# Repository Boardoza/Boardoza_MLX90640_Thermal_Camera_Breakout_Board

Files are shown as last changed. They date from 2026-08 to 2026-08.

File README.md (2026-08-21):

# Boardoza MLX90640 Thermal Camera Breakout Board

The **Boardoza MLX90640 Breakout Board** is a compact and high-performance **thermal imaging sensor board** built around the **Melexis MLX90640** far-infrared sensor array. Featuring a **32x24 pixel thermal resolution**, this breakout board delivers **768 independent temperature measurement points** for accurate non-contact thermal analysis and heat mapping applications.

Designed for compatibility with both **3.3V and 5V systems**, the board communicates through a high-speed **I<sup>2</sup>C interface** and supports refresh rates up to **64Hz**. With its wide temperature sensing range and integrated thermal array, the MLX90640 is ideal for applications such as industrial monitoring, predictive maintenance, occupancy detection, smart home systems, thermal visualization, robotics, and embedded sensing solutions.

## [Click here to purchase!](https://www.ozdisan.com/ureticiler/boardoza)

| Front Side | Back Side |
|:---:|:---:|
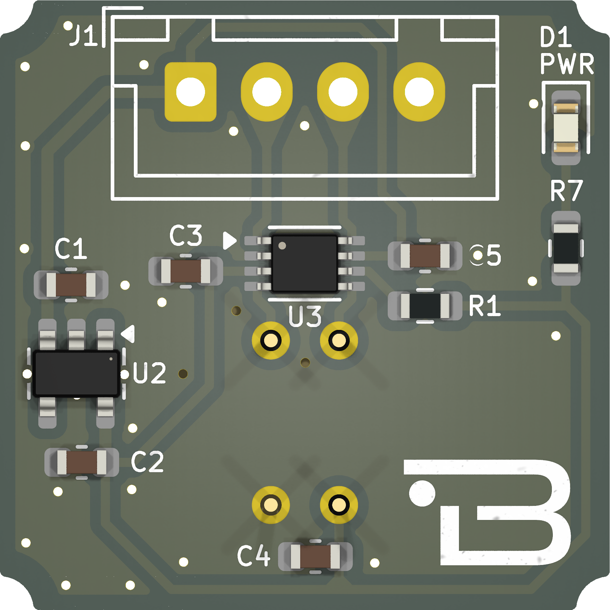
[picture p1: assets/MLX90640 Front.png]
MLX90640 Front
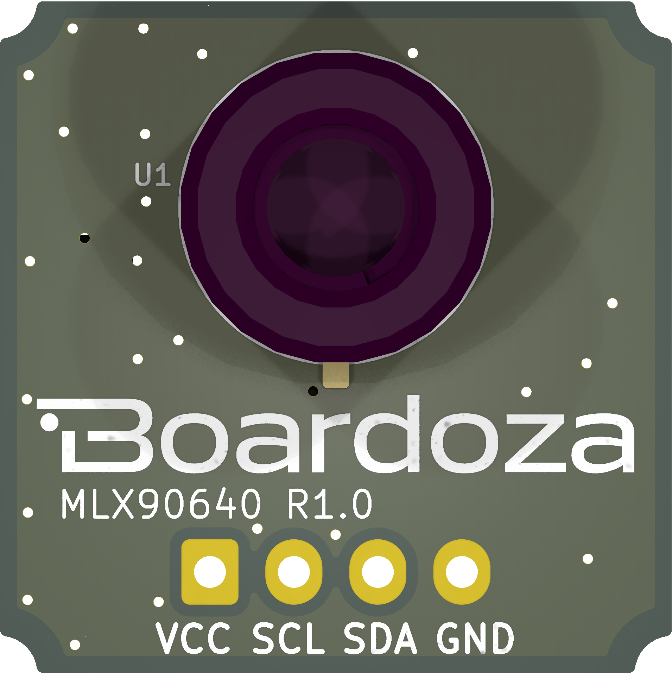
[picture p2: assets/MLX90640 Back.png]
MLX90640 Back
|  |  |

---

## Key Features

- **32x24 Thermal Imaging Array:** Captures 768 individual infrared temperature points for detailed thermal analysis.
- **Wide Temperature Measurement Range:** Measures object temperatures from **-40°C to +300°C** without physical contact.
- **Integrated Thermal Camera Functionality:** Enables compact thermal vision applications without requiring external optics.
- **Fast Refresh Rates:** Adjustable frame rates from **0.5Hz to 64Hz** for dynamic thermal monitoring.
- **Wide Compatibility:** Supports both **3.3V and 5V logic systems** for easy integration with popular development boards.
- **I<sup>2</sup>C Communication:** Supports I<sup>2</sup>C speeds up to **1MHz** for responsive thermal data transfer.
- **Wide Field of View:** Provides a **55° horizontal (X-axis)** and **35° vertical (Y-axis)** viewing angle for broader thermal coverage.  

---

## Technical Specifications

**Model:** MLX90640  
**Manufacturer:** Boardoza  
**Manufacturer IC:** Melexis  
**Functions:** Far-Infrared Thermal Imaging Sensor Array  
**Sensor Resolution:** 32 x 24 Pixels (768 Pixels Total)  
**Measurement Range:** -40°C to +300°C  
**Field of View (FoV):** 55° (X-axis) × 35° (Y-axis)  
**Interface:** I<sup>2</sup>C  
**I<sup>2</sup>C Clock Speed:** Up to 1 MHz  
**Refresh Rate:** 0.5Hz to 64Hz  
**Supply Voltage (VCC):** 3.3V to 5.5V DC  
**Logic Voltage Level:** 3.3V / 5V Compatible  
**Typical Current Consumption:** Less than 25mA   
**Operating Temperature:** -40°C to +85°C  
**Board Dimensions:** 20mm x 20mm  

---

## Board Pinout

### ( J1 ) I<sup>2</sup>C Connector

| Pin Number | Pin Name | Description |
|:---:|:---:|---|
| 1 | VCC | Voltage Supply Input |
| 2 | SCL | I<sup>2</sup>C Serial Clock |
| 3 | SDA | I<sup>2</sup>C Serial Data |
| 4 | GND | Ground |

---

## Board Dimensions

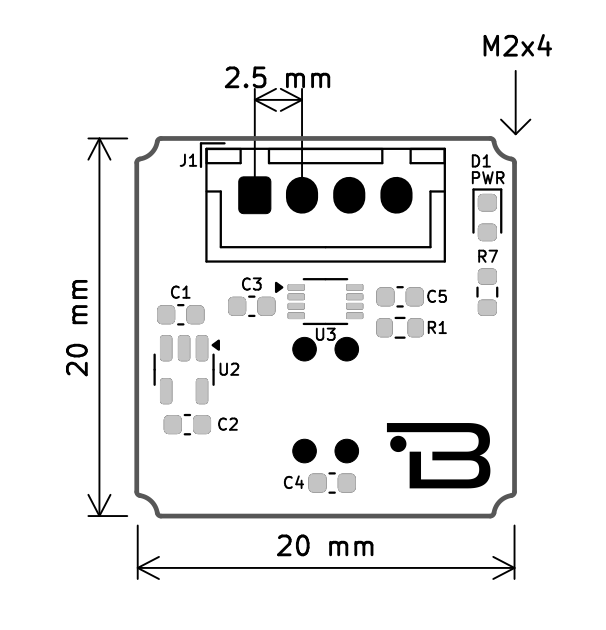
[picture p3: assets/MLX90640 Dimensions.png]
MLX90640 Board Dimensions


---

## Step Files

[Boardoza MLX90640.step](./assets/MLX90640%20Step.step)

---

## Datasheet

[MLX90640 Datasheet.pdf](./assets/MLX90640%20Datasheet.pdf)  
[TLV73333PDBVR Datasheet.pdf](./assets/TLV73333PDBVR%20Datasheet.pdf)  
[TXS0102DCU Datasheet.pdf](./assets/TXS0102DCU%20Datasheet.pdf)  

---

## Version History

- V1.0.0 - Initial Release

---

## Support

- If you have any questions or need support, please contact <support@boardoza.com>

---

## **License**

This repository contains both hardware and software components:

### **Hardware Design**

[][cc-by-sa]

All hardware design files are licensed under [Creative Commons Attribution-ShareAlike 4.0 International License][cc-by-sa].

[cc-by-sa]: http://creativecommons.org/licenses/by-sa/4.0/
[cc-by-sa-shield]: https://img.shields.io/badge/License-CC%20BY--SA%204.0-lightgrey.svg

### **Software/Firmware**

[][bsd]

All software and firmware are licensed under [BSD 3-Clause License][bsd].

[bsd]: https://opensource.org/licenses/BSD-3-Clause
[bsd-shield]: https://img.shields.io/badge/License-BSD%203--Clause-blue.svg

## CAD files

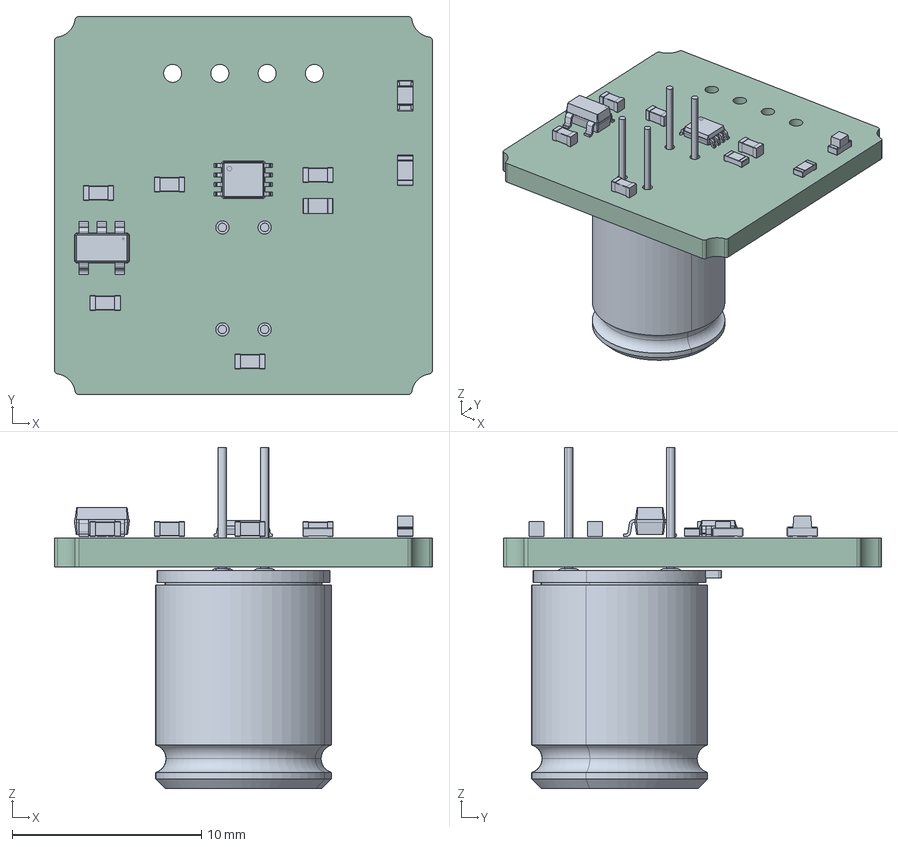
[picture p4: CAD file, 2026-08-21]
assets/MLX90640 Step.step
20.0 x 20.0 x 18.1 mm
R_0603_1608Metric x 2
VSSOP-8_2.3x2mm_P0.5mm
C_0603_1608Metric x 5
LED_0603_1608Metric
SOT-23-5
kicad_embedded_38222028E3E54F88FE30E4AF7AF088A7
kibot_x39tdho__PCB

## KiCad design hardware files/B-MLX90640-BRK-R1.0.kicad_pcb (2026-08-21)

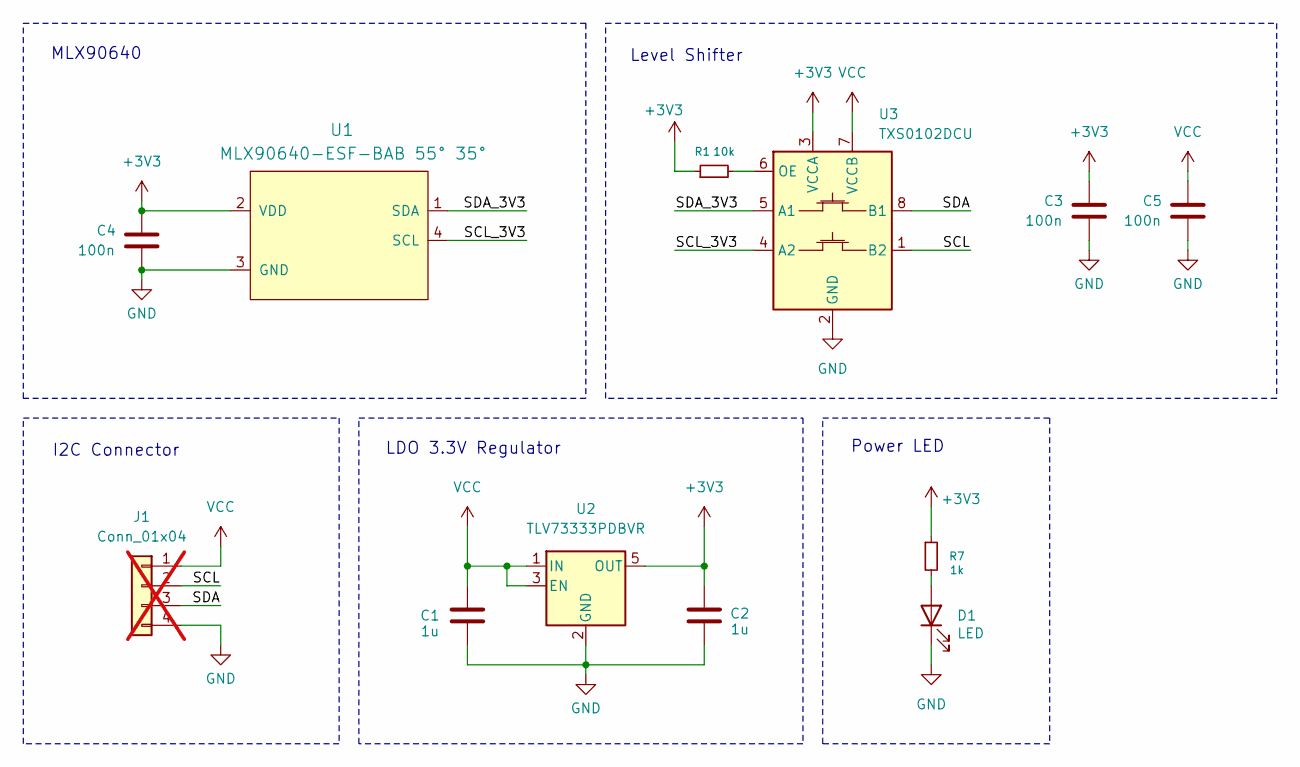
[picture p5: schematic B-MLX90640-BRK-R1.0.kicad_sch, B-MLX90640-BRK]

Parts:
C1, C2: 1u; C_0603_1608Metric; MANUFACTURER PART CL10A105KO8NNNC
C3, C4, C5: 100n; C_0603_1608Metric; MPN CL10B104KB8WPNC
D1: LED; LED_0603_1608Metric; MANUFACTURER PART LTST-C190KRKT
J1: Conn_01x04; JST_XH_B4B-XH-A_1x04_P2.50mm_Vertical; MPN L-KLS1-2.50-04-SB; not fitted
R1: 10k; R_0603_1608Metric; MANUFACTURER PART 0603SAJ0471T5E
R7: 1k; R_0603_1608Metric; MANUFACTURER PART 0603SAJ0471T5E
U1: MLX90640-ESF-BAB 55° 35°; MLX90640ESFBAB000TU; MPN MLX90640ESF-BAB-000-TU
U2: TLV73333PDBVR; SOT-23-5; MANUFACTURER PART TLV73333PDBVR
U3: TXS0102DCU; VSSOP-8_2.3x2mm_P0.5mm; MPN TXS0102DCUR

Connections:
+3V3: C2.1, C3.2, C4.2, R1.1, R7.1, U1.2 (VDD), U2.5 (OUT), U3.3 (VCCA)
/SCL: J1.2, U3.1 (B2)
/SCL_3V3: U1.4 (SCL), U3.4 (A2)
/SDA: J1.3, U3.8 (B1)
/SDA_3V3: U1.1 (SDA), U3.5 (A1)
GND: C1.1, C2.2, C3.1, C4.1, C5.1, D1.1 (K), J1.4, U1.3 (GND), U2.2 (GND), U3.2 (GND)
unnamed: D1.2 (A), R7.2
unnamed: R1.2, U3.6 (OE)
VCC: C1.2, C5.2, J1.1, U2.1 (IN), U2.3 (EN), U3.7 (VCCB)

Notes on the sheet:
LDO 3.3V Regulator
MLX90640
Power LED
Level Shifter
I2C Connector

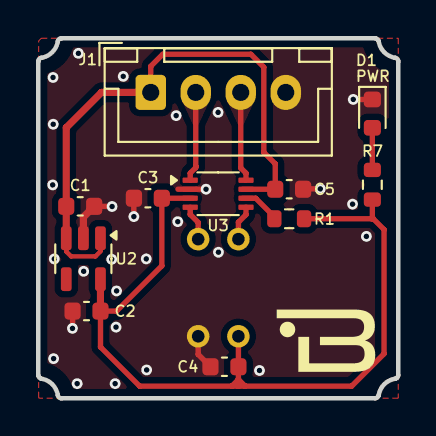
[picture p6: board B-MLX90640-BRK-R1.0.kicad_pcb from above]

Board: 2 copper layers, 20.0 x 20.0 mm, 12 parts (1 on the bottom side), 9 nets.

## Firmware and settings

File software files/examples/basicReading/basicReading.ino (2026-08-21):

/*
  Read the temperature pixels from the MLX90640 IR array
  By: Nathan Seidle
  SparkFun Electronics
  Date: May 22nd, 2018
  License: MIT. See license file for more information but you can
  basically do whatever you want with this code.

  Feel like supporting open source hardware?
  Buy a board from SparkFun! https://www.sparkfun.com/products/14769

  This example initializes the MLX90640 and outputs the 768 temperature values
  from the 768 pixels.

  This example will work with a Teensy 3.1 and above. The MLX90640 requires some
  hefty calculations and larger arrays. You will need a microcontroller with 20,000
  bytes or more of RAM.

  This relies on the driver written by Melexis and can be found at:
  https://github.com/melexis/mlx90640-library

  Hardware Connections:
  Connect the SparkFun Qwiic Breadboard Jumper (https://www.sparkfun.com/products/14425)
  to the Qwiic board
  Connect the male pins to the Teensy. The pinouts can be found here: https://www.pjrc.com/teensy/pinout.html
  Open the serial monitor at 9600 baud to see the output
*/

#include <Wire.h>

#include "MLX90640_API.h"
#include "MLX90640_I2C_Driver.h"

const byte MLX90640_address = 0x33; //Default 7-bit unshifted address of the MLX90640

#define TA_SHIFT 8 //Default shift for MLX90640 in open air

static float mlx90640To[768];
paramsMLX90640 mlx90640;

void setup()
{
  Wire.begin();
  Wire.setClock(400000); //Increase I2C clock speed to 400kHz

  Serial.begin(9600);
  while (!Serial); //Wait for user to open terminal
  Serial.println("MLX90640 IR Array Example");

  if (isConnected() == false)
  {
    Serial.println("MLX90640 not detected at default I2C address. Please check wiring. Freezing.");
    while (1);
  }
  Serial.println("MLX90640 online!");

  //Get device parameters - We only have to do this once
  int status;
  uint16_t eeMLX90640[832];
  status = MLX90640_DumpEE(MLX90640_address, eeMLX90640);
  if (status != 0)
    Serial.println("Failed to load system parameters");

  status = MLX90640_ExtractParameters(eeMLX90640, &mlx90640);
  if (status != 0)
    Serial.println("Parameter extraction failed");

  //Once params are extracted, we can release eeMLX90640 array
}

void loop()
{
  for (byte x = 0 ; x < 2 ; x++) //Read both subpages
  {
    uint16_t mlx90640Frame[834];
    int status = MLX90640_GetFrameData(MLX90640_address, mlx90640Frame);
    if (status < 0)
    {
      Serial.print("GetFrame Error: ");
      Serial.println(status);
    }

    float vdd = MLX90640_GetVdd(mlx90640Frame, &mlx90640);
    float Ta = MLX90640_GetTa(mlx90640Frame, &mlx90640);

    float tr = Ta - TA_SHIFT; //Reflected temperature based on the sensor ambient temperature
    float emissivity = 0.95;

    MLX90640_CalculateTo(mlx90640Frame, &mlx90640, emissivity, tr, mlx90640To);
  }

  for (int x = 0 ; x < 10 ; x++)
  {
    Serial.print("Pixel ");
    Serial.print(x);
    Serial.print(": ");
    Serial.print(mlx90640To[x], 2);
    Serial.print("C");
    Serial.println();
  }

  delay(1000);
}

//Returns true if the MLX90640 is detected on the I2C bus
boolean isConnected()
{
  Wire.beginTransmission((uint8_t)MLX90640_address);
  if (Wire.endTransmission() != 0)
    return (false); //Sensor did not ACK
  return (true);
}

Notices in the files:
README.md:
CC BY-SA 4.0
